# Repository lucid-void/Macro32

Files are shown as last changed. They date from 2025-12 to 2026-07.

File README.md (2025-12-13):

# Macro32

The Macro32 is a macropad featuring a stm32.
This project was a way for me to learn how to integrate an IC of my choosing on my PCB.
It was also my fist project using kicad

Image of the macropad

## Take a look

[kicad project](https://kicanvas.org/?github=https://github.com/KillrOfLife/Macro32/blob/main/PCB/macro32.kicad_pro)

## How can I make it myself

Great question!
Go look in the github releases for the latest tag
There you should find the downloads for the PCB production files (aka gerbers)
And the STL's for the case parts if you want that too. (you may need to download the source code)

## How to assemble

For any help assembling this macropad refer to the [build guide](https://github.com/KillrOfLife/Macro32/blob/main/buildguide.md).

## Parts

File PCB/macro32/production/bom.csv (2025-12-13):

Designator | Footprint | Quantity | Value | LCSC Part #
D1, D10, D11, D12, D13, D14, D15, D16, D17, D18, D19, D2, D20, D21, D22, D3, D4, D5, D6, D7, D8, D9 | SMD_SOD123_Leaded | 22 | Diode
J1 | OLED_4Pin | 1 | OLED
J2 | OLED_5Pin | 1 | OLED
J3, J5 | fakemag4pin90degFemale | 2 | Magnetic connector
J4, J6 | fakemag4pin90degMale | 2 | Magnetic connector
R1, R2 | 0805 | 2 | 10k
S1, S18 | keyswitch_cherrymx_hotswap_1u_rotary_encoder_ec12 | 2 | Rotary_Encoder_Switch
S10, S11, S12, S13, S14, S15, S16, S17, S19, S2, S20, S21, S22, S3, S4, S5, S6, S7, S8, S9 | Hotswap_MX_Plated_1.00u | 20 | Keyswitch
SW1 | SW_SPST_TS-1088-xR020 | 1 | RST
U1 | SuperMini_NRF52850_pro_micro | 1 | SuperMini_NRF52840

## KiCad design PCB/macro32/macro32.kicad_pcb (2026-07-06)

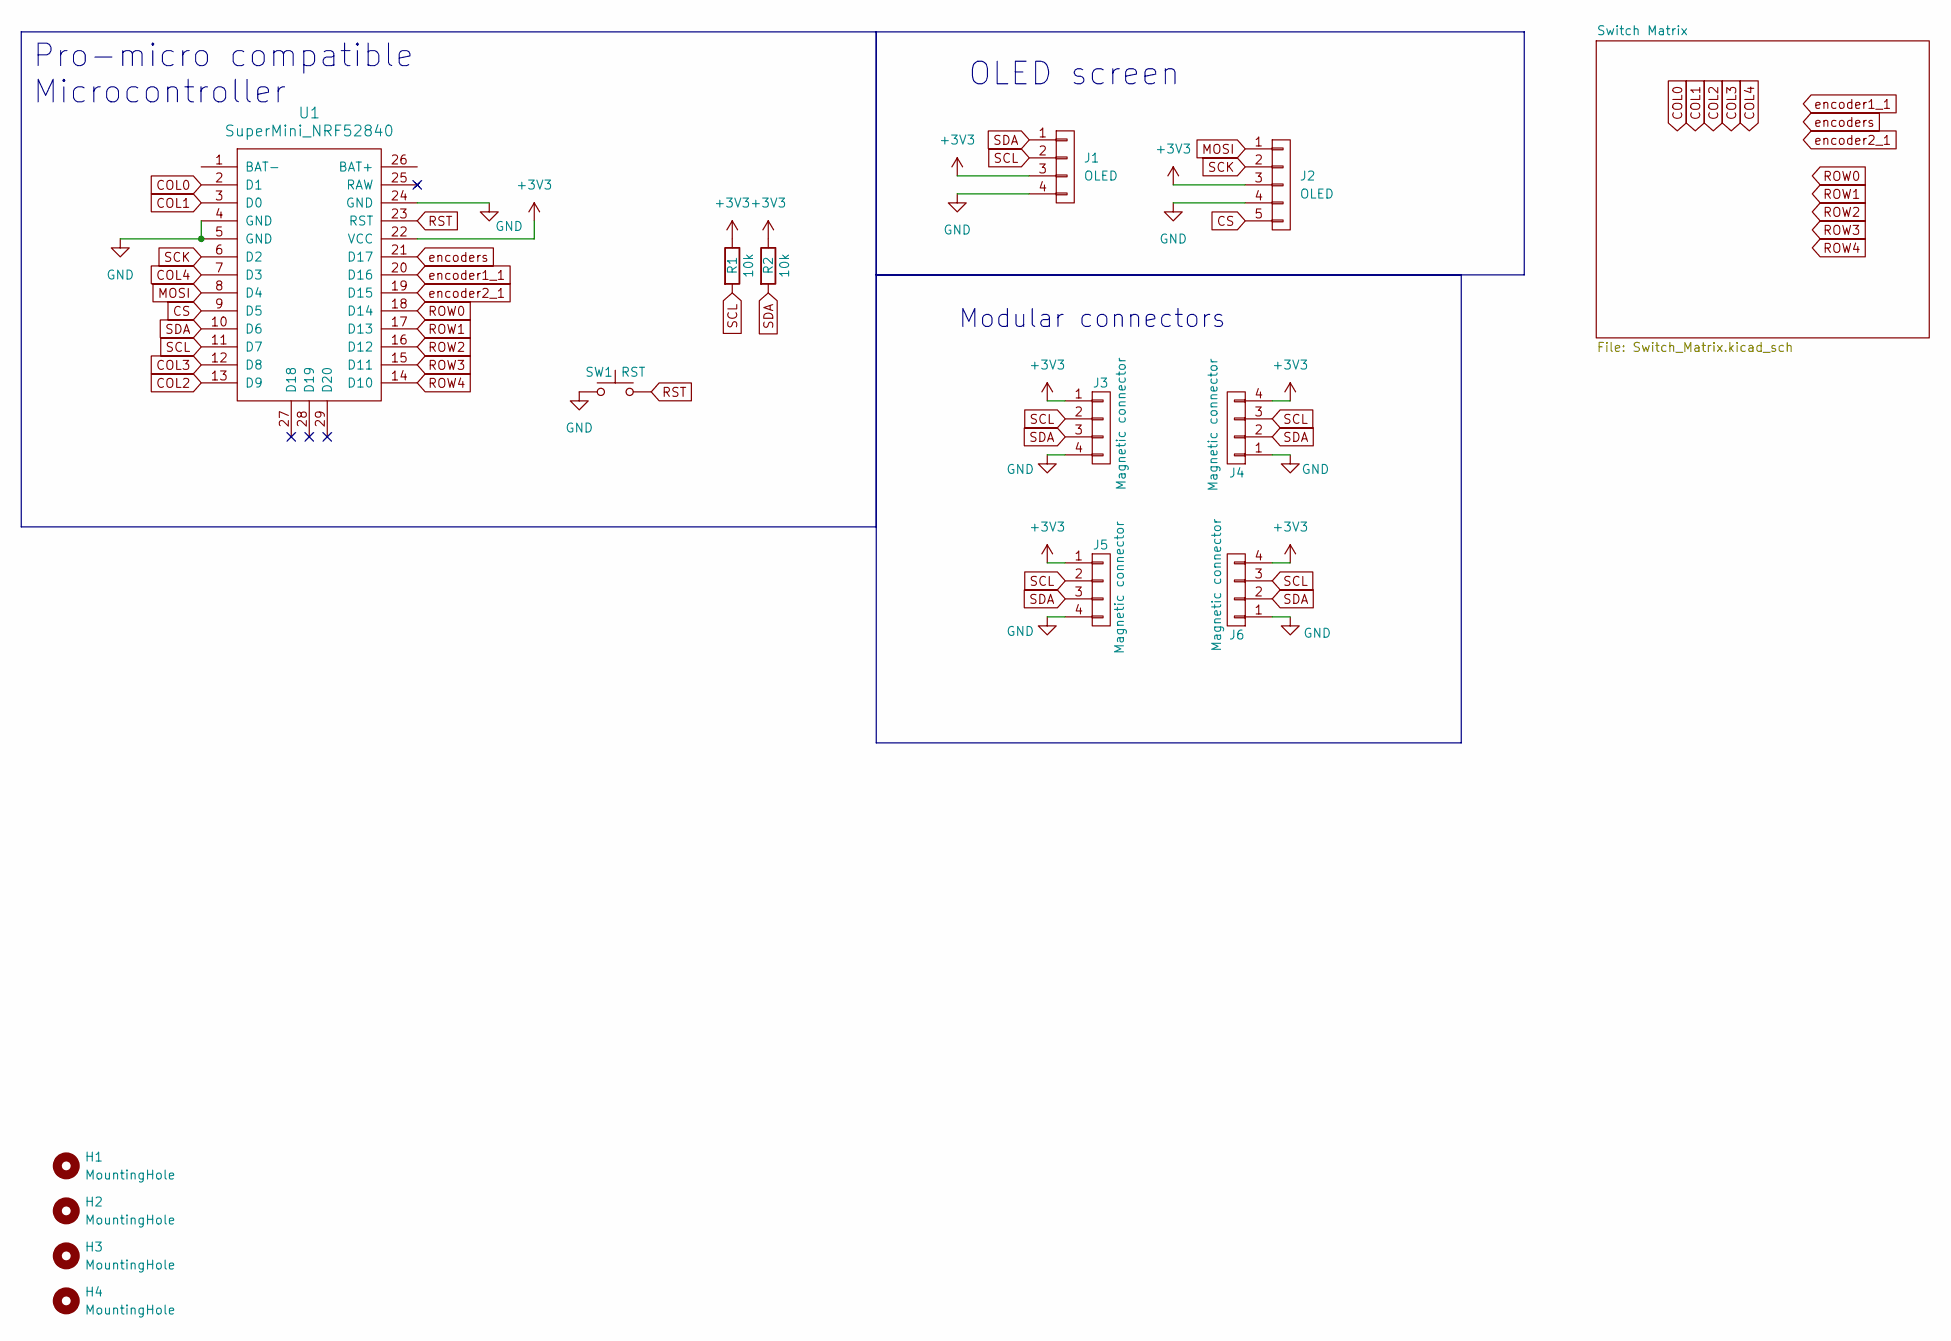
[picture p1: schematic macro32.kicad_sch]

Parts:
H1, H2, H3, H4: MountingHole; MountingHole_3.2mm_M3
J1: OLED; OLED_4Pin
J2: OLED; OLED_5Pin
J3, J5: Magnetic connector; fakemag4pin90degFemale
J4, J6: Magnetic connector; fakemag4pin90degMale
R1, R2: 10k; R_0805_2012Metric_Pad1.20x1.40mm_HandSolder
SW1: RST; SW_SPST_TS-1088-xR020
U1: SuperMini_NRF52840; SuperMini_NRF52850_pro_micro

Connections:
+3V3: J1.3, J2.3, J3.1, J4.4, J5.1, J6.4, R1.1, R2.1, U1.22 (VCC)
COL0: U1.2 (D1); also elsewhere on the board
COL1: U1.3 (D0); also elsewhere on the board
COL2: U1.13 (D9); also elsewhere on the board
COL3: U1.12 (D8); also elsewhere on the board
COL4: U1.7 (D3); also elsewhere on the board
CS: J2.5 (P4), U1.9 (D5)
GND: J1.4, J2.4, J3.4, J4.1, J5.4, J6.1, SW1.1, U1.4 (GND), U1.5 (GND), U1.24 (GND); also elsewhere on the board
MOSI: J2.1, U1.8 (D4)
ROW0: U1.18 (D14); also elsewhere on the board
ROW1: U1.17 (D13); also elsewhere on the board
ROW2: U1.16 (D12); also elsewhere on the board
ROW3: U1.15 (D11); also elsewhere on the board
ROW4: U1.14 (D10); also elsewhere on the board
RST: SW1.2, U1.23 (RST)
SCK: J2.2, U1.6 (D2)
SCL: J1.2, J3.2, J4.3, J5.2, J6.3, R1.2, U1.11 (D7)
SDA: J1.1, J3.3, J4.2, J5.3, J6.2, R2.2, U1.10 (D6)
encoder1_1: U1.20 (D16); also elsewhere on the board
encoder2_1: U1.19 (D15); also elsewhere on the board
encoders: U1.21 (D17); also elsewhere on the board

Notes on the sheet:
Pro-micro compatible Microcontroller
Modular connectors
OLED screen

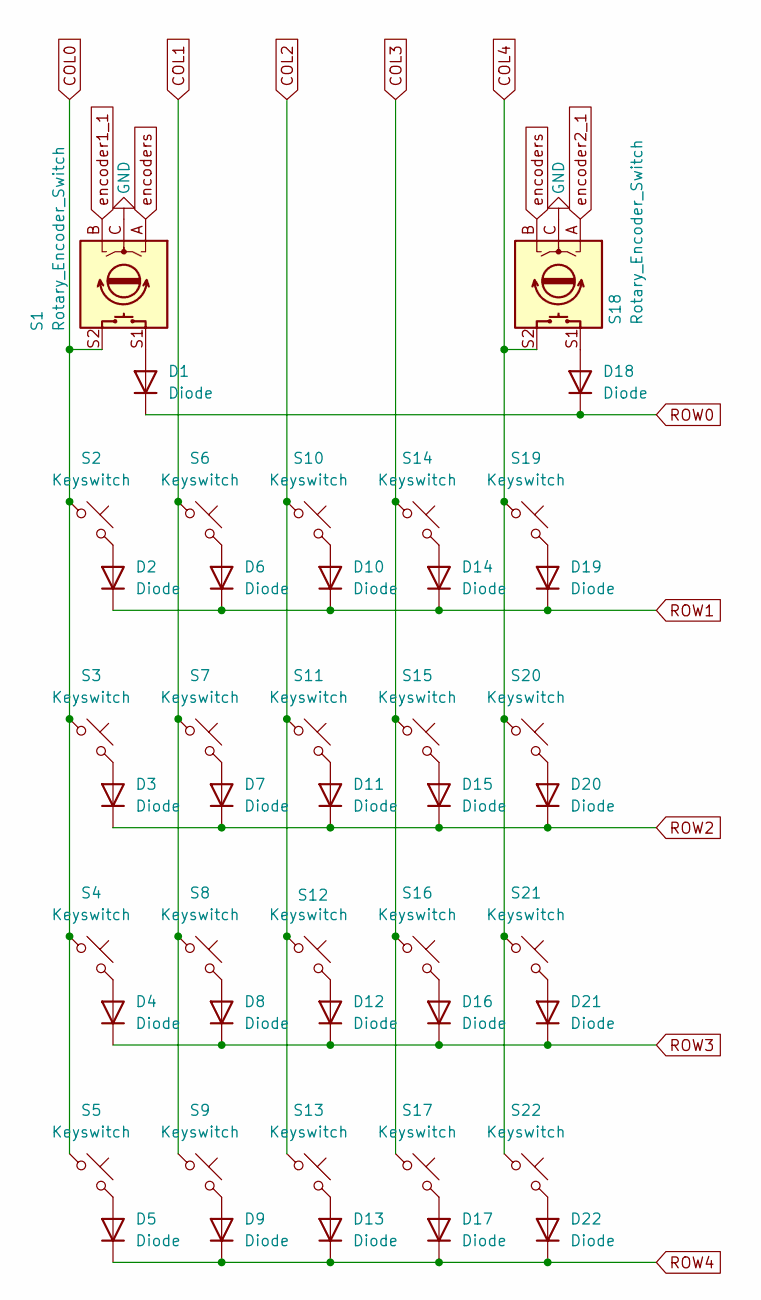
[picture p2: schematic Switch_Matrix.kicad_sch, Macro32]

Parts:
D1, D2, D3, D4, D5, D6, D7, D8, D9, D10, D11, D12, D13, D14, D15, D16, D17, D18, D19, D20, D21, D22: Diode; SMD_SOD123_Leaded
S1, S18: Rotary_Encoder_Switch; keyswitch_cherrymx_hotswap_1u_rotary_encoder_ec12
S2, S3, S4, S5, S6, S7, S8, S9, S10, S11, S12, S13, S14, S15, S16, S17, S19, S20, S21, S22: Keyswitch; Hotswap_MX_Plated_1.00u

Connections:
COL0: S1.S2, S2.1, S3.1, S4.1, S5.1; also elsewhere on the board
COL1: S6.1, S7.1, S8.1, S9.1; also elsewhere on the board
COL2: S10.1, S11.1, S12.1, S13.1; also elsewhere on the board
COL3: S14.1, S15.1, S16.1, S17.1; also elsewhere on the board
COL4: S18.S2, S19.1, S20.1, S21.1, S22.1; also elsewhere on the board
GND: S1.C, S18.C; also elsewhere on the board
unnamed: D1.2 (A), S1.S1
unnamed: D2.2 (A), S2.2
unnamed: D3.2 (A), S3.2
unnamed: D4.2 (A), S4.2
unnamed: D5.2 (A), S5.2
unnamed: D6.2 (A), S6.2
unnamed: D7.2 (A), S7.2
unnamed: D8.2 (A), S8.2
unnamed: D9.2 (A), S9.2
unnamed: D10.2 (A), S10.2
unnamed: D11.2 (A), S11.2
unnamed: D12.2 (A), S12.2
unnamed: D13.2 (A), S13.2
unnamed: D14.2 (A), S14.2
unnamed: D15.2 (A), S15.2
unnamed: D16.2 (A), S16.2
unnamed: D17.2 (A), S17.2
unnamed: D18.2 (A), S18.S1
unnamed: D19.2 (A), S19.2
unnamed: D20.2 (A), S20.2
unnamed: D21.2 (A), S21.2
unnamed: D22.2 (A), S22.2
ROW0: D1.1 (K), D18.1 (K); also elsewhere on the board
ROW1: D2.1 (K), D6.1 (K), D10.1 (K), D14.1 (K), D19.1 (K); also elsewhere on the board
ROW2: D3.1 (K), D7.1 (K), D11.1 (K), D15.1 (K), D20.1 (K); also elsewhere on the board
ROW3: D4.1 (K), D8.1 (K), D12.1 (K), D16.1 (K), D21.1 (K); also elsewhere on the board
ROW4: D5.1 (K), D9.1 (K), D13.1 (K), D17.1 (K), D22.1 (K); also elsewhere on the board
encoder1_1: S1.B; also elsewhere on the board
encoder2_1: S18.A; also elsewhere on the board
encoders: S1.A, S18.B; also elsewhere on the board

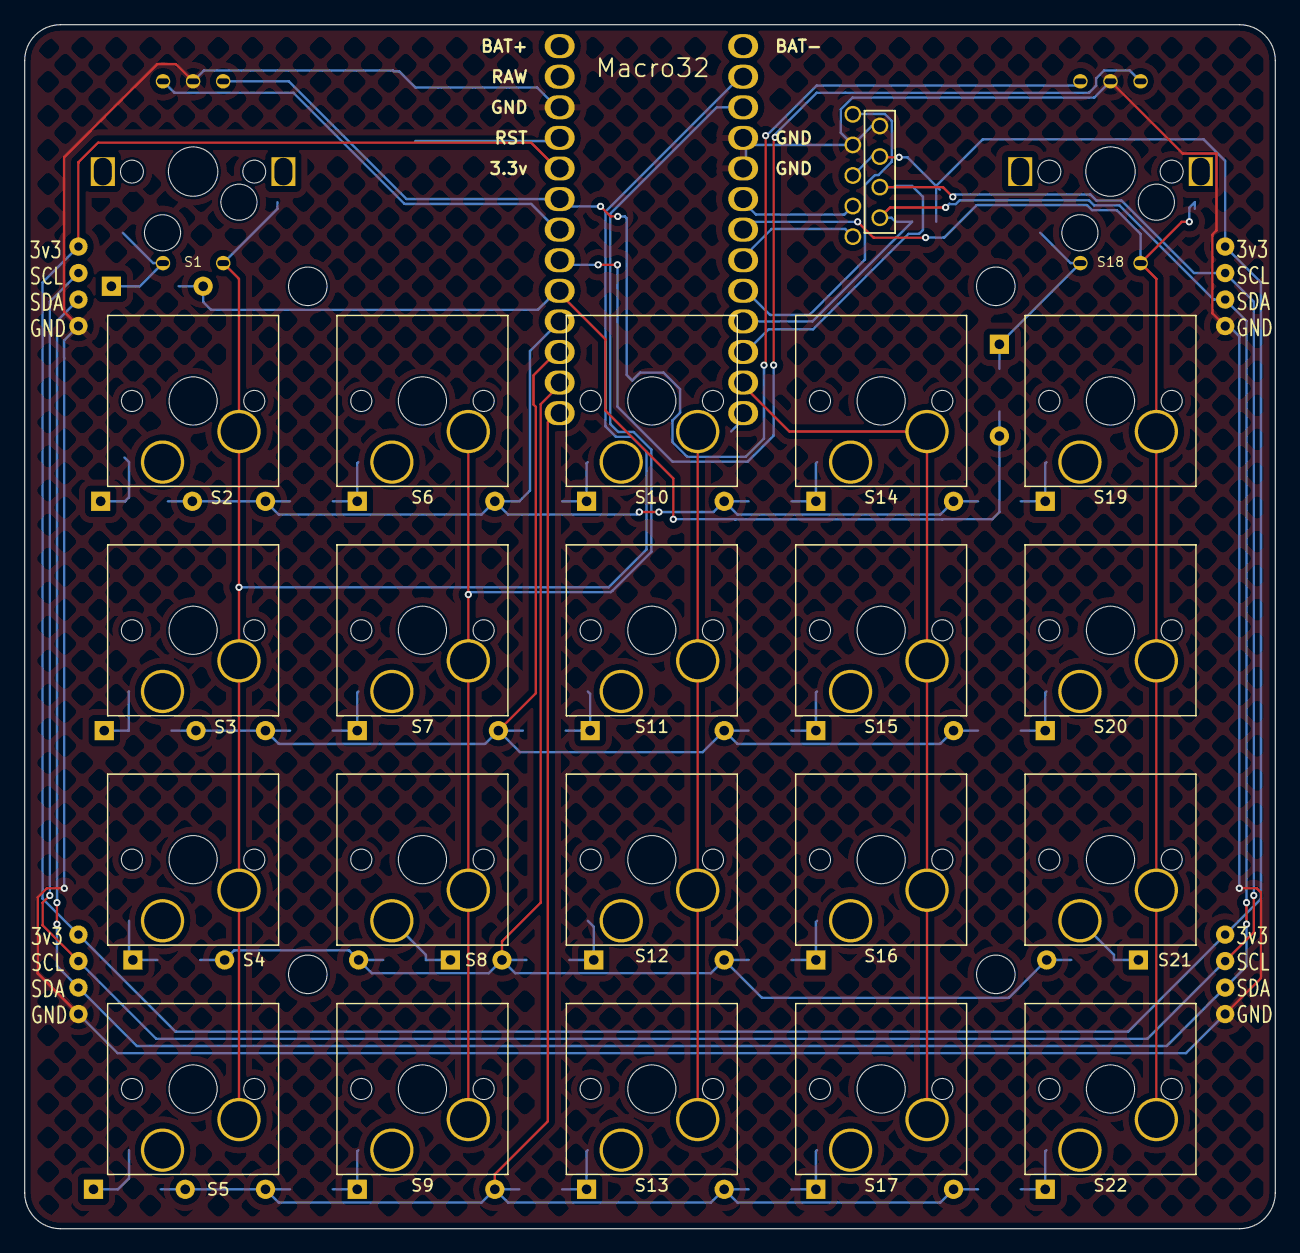
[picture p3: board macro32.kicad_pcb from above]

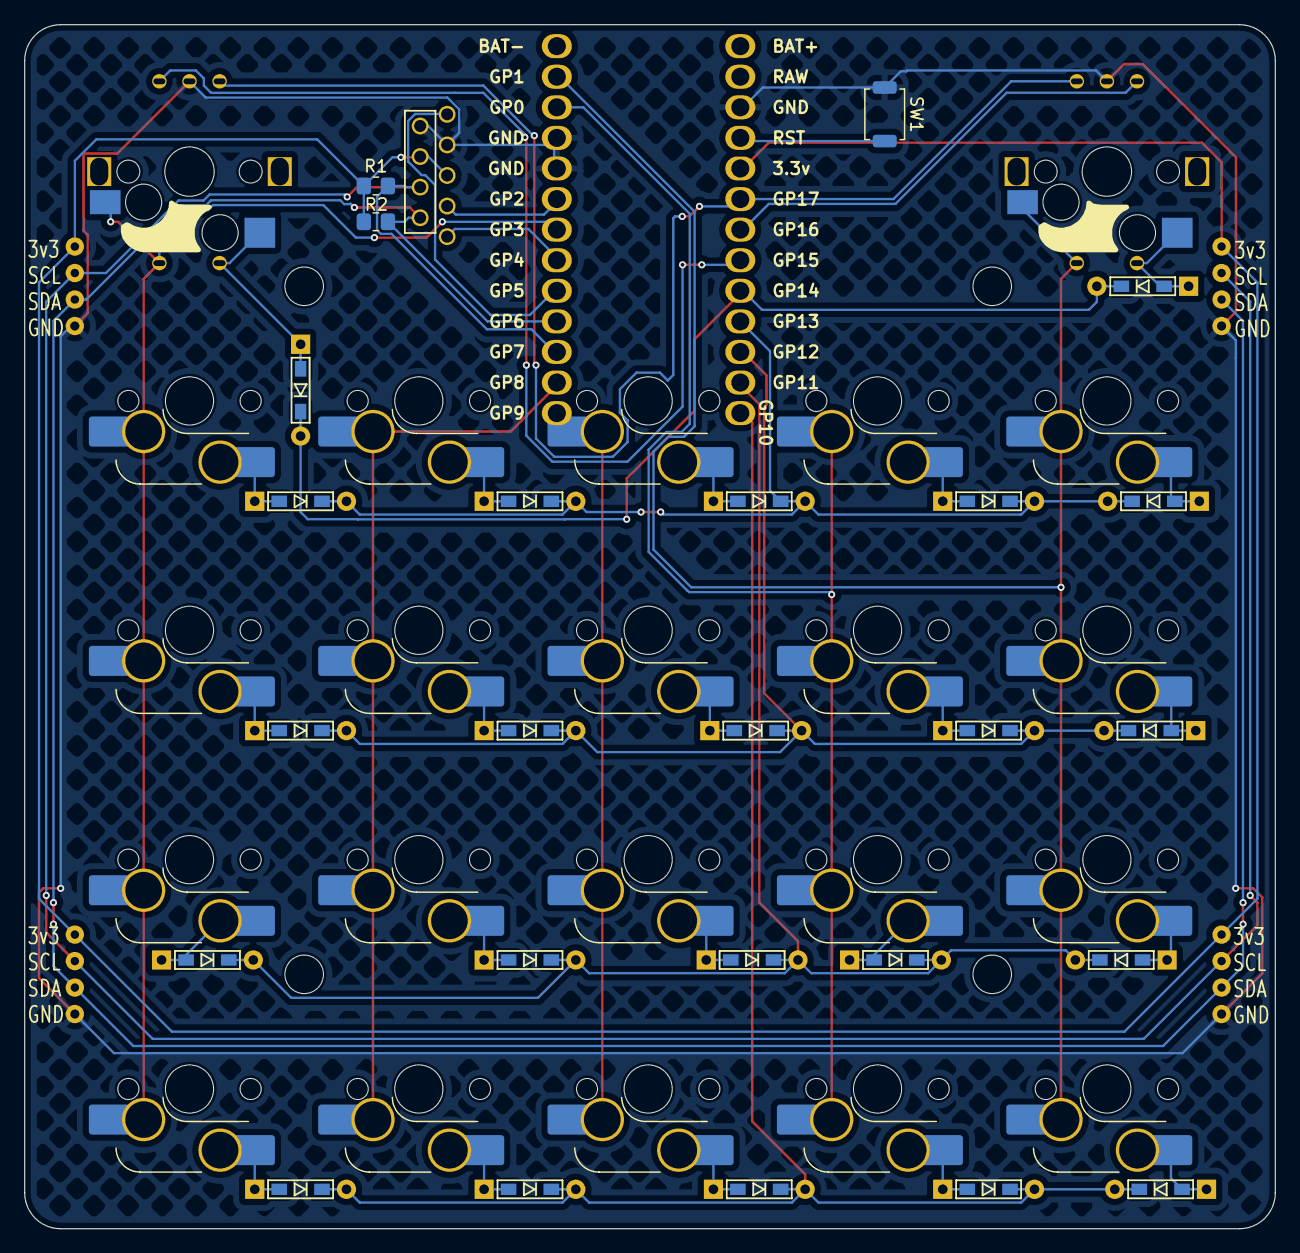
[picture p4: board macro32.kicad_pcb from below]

Board: 2 copper layers, 103.9 x 100.0 mm, 58 parts (28 on the bottom side), 43 nets.

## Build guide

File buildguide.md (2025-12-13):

# Build Guide

This is the build guide for the Macro32

Image of the macropad

## Parts

### PCB components - Required

| Name | Count | Remarks |
|:---|:---|:---|
| Ceramic capacitor 4.7uF | 1 | 4.7uF with 0805 footprint |
| Ceramic capacitor 1uF | 3 | 1uF with 0805 footprint |
| Ceramic capacitor 100nF | 7 | 100nF with 0805 footprint |
| Diode SOD-123 | 14 | |
| Fuse 500mA | 1 | Optional but reccomended |
| USB-C port | 1 | USB4110 |
| Resistor 10k | 1 | 0805 footprint |
| Resistor 5.1k | 2 | 0805 footprint |
| MX hotswap socket | 12 - 14  | depending if you want rotary encoders |
| tiny switch | 2 | SW_SPST_TS-1088-xR020 |
| STM32F072 | 1 | LQFP48 format |
| voltage regulator | 1 | XC6206PxxxMR SOT-23-3 footprint |
| --------------------------- | -------- | ------------------------------------  |
| ec12 rotary encoder | 0 - 2 | |
| LED | 4 | WS2812B for underglow |
| LED Line driver | 1 | 74AHC1G125 SOT-353 footprint |
| Resistor 100k | 1 | 0805 footprint (for LED) |

### Special case

!!!! ONLY IN V1
Due to a mistake in the shematic the USB ESD protector was inproperly connected.
This means the USB ESD protection is not needed in V1.

| Name | Count | Remarks |
|:---|:---|:---|
| USB ESD protection | 1 | USBLC6-2P6 SOT-666 footprint |

### Full build components

| Name | Count | Remarks |
|:---|:---|:---|
| PCB | 1 | |
| Case | 1 | Top and bottom |
| Switch plate | 1 | FR4 1.6mm thick or 3d printed |
| Key switches | 12 - 14 | Only Cherry MX compatible |
| Keycaps | 12 - 14 | 1u |
| Screw M3x8 | 8 | For Case assembly |
| Type-C cable | 1 | |
| ----------------------- | --------------- | --------------------------- |
| Rotary Encoder knobs | 0 - 2 pieces | |

## Firmware preparation

Please see [firmware.md](./firmware.md).

## Build

I'll be starting the guide from an unpopulated PCB
If you let jlcpcb or similar populate the PCB for you then skip to part !TODO
<!-- TODO -->

### 1. Make sure you have all the components to populate the PCB

Components can be found in the [BOM](https://raw.githubusercontent.com/KillrOfLife/Macro32/refs/heads/main/PCB/production/bom.csv) or above in the components list.

You can make the choice between having 14 switches and no rotary encoders or 12 switches with rotary encoders.
The rotary encoders are wired as such that you can place encoders with a built in switch.

!!!! ONLY IN V1
Due to a mistake in the shematic the USB ESD protector was inproperly connected.
This means the USB ESD protection is not needed in V1.

bare PCB front
bare PCB back

### 2. Place Components

1. In case you have a stencil, use it with some solder paste to apply solder paste on the pads of the bottom of the PCB.
This makes assembly easier than soldering all the small components by hand.

2. Place the components on the board
I recommend placing small components, the USB-C header and the microcontroller in this step
3. use a heat gun or heatplate to melt the solder.
4. Place your Cherry MX hostwap sockets on the board and give them a little touch with your soldering iron.
5. now you can insert your rotary encoders on the FRONT SIDE OF THE BOARD and solder the connectors on the back.
6. Your PCB should now look something like this

    Populated PCB back

    Theres one more step to go, manually fix my mistake and solder a few pads with some wire

7. connect the pads of U2 (the ESD protector) to make sure the USB data can pass to the microcontroller (follow the yellow to connect the pads)

    U2 fix

Your PCB should now be working!
go ahead and flash some firmware [firmware.md](./firmware.md).

### 3. Assemble
<!-- more images incoming for assembly process -->

1. Attach the switches to the switch plate.

2. Add the PCB to the bottom of the switches.

3. Screw the switch plate to the top of the chassis.

4. Add the bottom of the chassis.

5. Screw the bottom to the top of the chassis.

6. Optional add some rubber feet

7. Go ahead and jazz it up with some colorful keycaps.

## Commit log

2025-11-20 Schematic and PCB v2.0 moved files to seperate folder
    [STM32_pro_micro.kicad_sch, Switch_Matrix.kicad_sch, bom.csv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]
2025-12-13 PCB V2 design
    [STM32_pro_micro.kicad_sch, Switch_Matrix.kicad_sch, bom.csv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]
